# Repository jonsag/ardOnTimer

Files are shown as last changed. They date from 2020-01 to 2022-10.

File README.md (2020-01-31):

# ardOnTimer
An on timer with relay, mainly for use in an UV exposure box.  

Time is set with buttons and visualized on an LCD display.  

When setting new time it's saved in eeprom and reloaded at startup.  

Timer range is from 10 seconds to 9 hours, 59 minutes and 59 seconds in 10 seconds steps.  
This can be changed in configuration file.  

Parts list
==========
1 x Arduino Uno, kjell.com art#88860  
1 x LCD display 2x16 characters, kjell.com art# 90215  
1 x Relay module KY-019, kjell.com art# 87878  
1 x Buzzer, kjell.com art# 87887  
4 x Switch, kjell.com art# 36011  
1 x 10kohm potentiometer  
4 x 10kohm resistor  
1 x 220ohm resistor  
1x 100ohm resistor  

Screens
==========
The timer has three screens.  
Second row on screens shows which buttons are active.  

Standby screen
----------
Waiting for start or set.  

 * Start/Stop/Store button to start timer and enter run screen.  
 * Set button to enter set screen.  

Run screen
----------
Shows spinning bar and time left on first row, and progressbar on the second.  

 * Start/Stop/Store button to stop timer and go back to standby screen.  

Set screen
----------
Setting timer.  

* Start/Stop/Store button to store set time.  
* Set button to exit back to standby screen. If set time was not stored, previous time will be used.  
* Up or Down button to increase/decrease time. Each press adds/subtracts 10 seconds from time. Long press adds/subtracts one minute from time. Holding down button keeps stepping minutes.

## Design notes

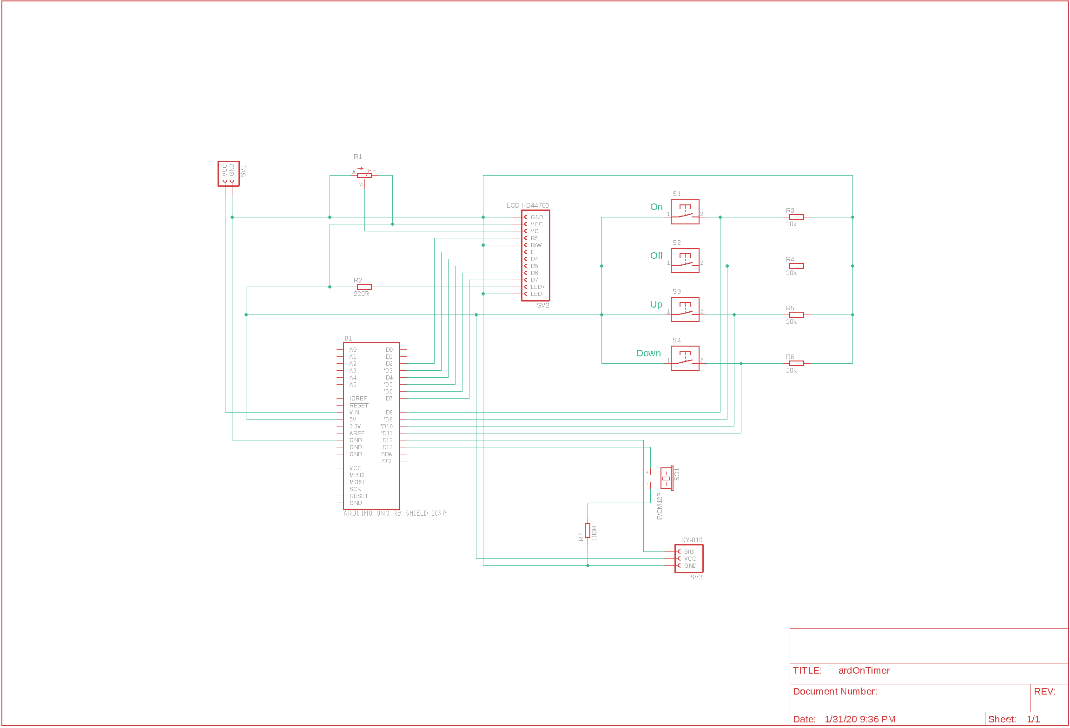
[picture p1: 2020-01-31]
Documents/ardOnTimer schematics.png

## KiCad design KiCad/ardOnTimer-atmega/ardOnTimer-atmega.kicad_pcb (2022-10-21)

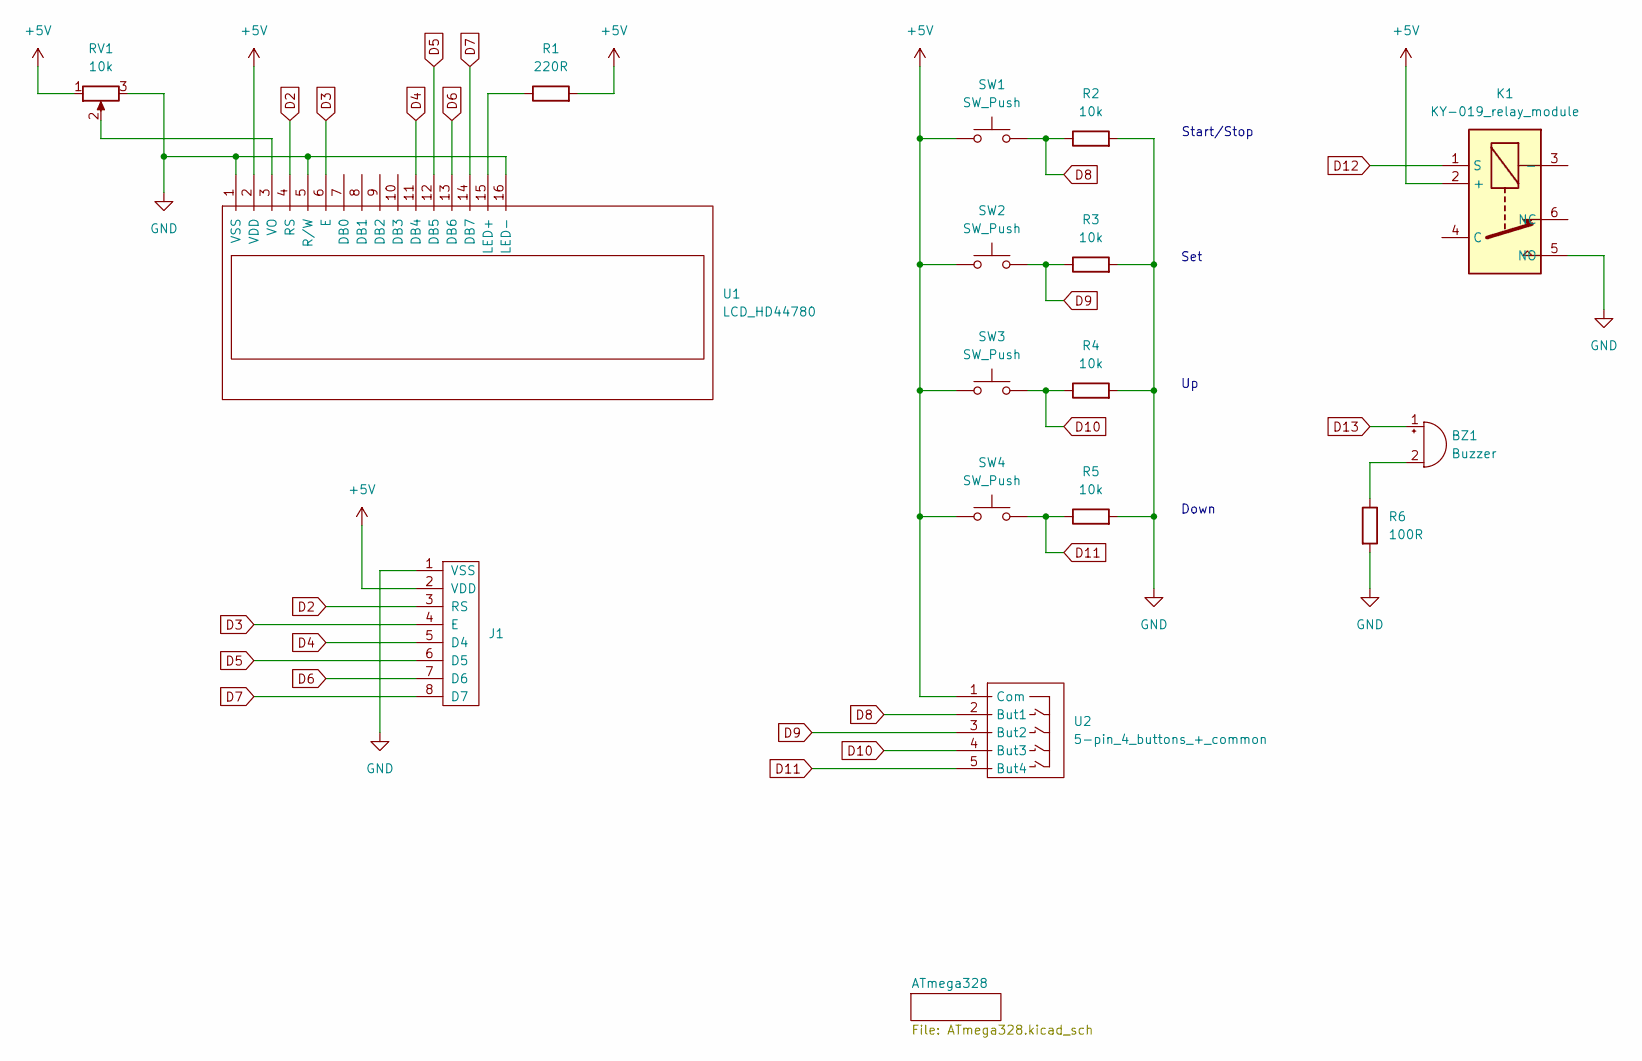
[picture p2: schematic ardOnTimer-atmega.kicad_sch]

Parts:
BZ1: Buzzer; Buzzer_TDK_PS1240P02BT_D12.2mm_H6.5mm_large
J1: 8-pin_header_LCD_interface; 8-pin JST LCD
K1: KY-019_relay_module; KY-019_Relay_module_w_header_large
R1: 220R; R_Axial_DIN0207_L6.3mm_D2.5mm_P10.16mm_Horizontal_larger_pa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
R2, R3, R4, R5: 10k; R_Axial_DIN0207_L6.3mm_D2.5mm_P10.16mm_Horizontal_larger_pa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
R6: 100R; R_Axial_DIN0207_L6.3mm_D2.5mm_P10.16mm_Horizontal_larger_pa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
RV1: 10k; Potentiometer_Bourns_3339P_Vertical_large
SW1, SW2, SW3, SW4: SW_Push; SW_PUSH_6mm_large
U1: LCD_HD44780; LCD_HD44780_16x2_w_headers_large
U2: 5-pin_4_buttons_+_common; 5-pin JST 4 buttons + common

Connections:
+5V: J1.2 (VDD), K1.2 (+), R1.2, RV1.1, SW1.1, SW2.1, SW3.1, SW4.1, U1.2 (VDD), U2.1 (Com); also elsewhere on the board
D2: J1.3 (RS), U1.4 (RS); also elsewhere on the board
D3: J1.4 (E), U1.6 (E); also elsewhere on the board
D4: J1.5 (D4), U1.11 (DB4); also elsewhere on the board
D5: J1.6 (D5), U1.12 (DB5); also elsewhere on the board
D6: J1.7 (D6), U1.13 (DB6); also elsewhere on the board
D7: J1.8 (D7), U1.14 (DB7); also elsewhere on the board
D8: R2.1, SW1.2, U2.2 (But1); also elsewhere on the board
D9: R3.1, SW2.2, U2.3 (But2); also elsewhere on the board
D10: R4.1, SW3.2, U2.4 (But3); also elsewhere on the board
D11: R5.1, SW4.2, U2.5 (But4); also elsewhere on the board
D12: K1.1 (S); also elsewhere on the board
D13: BZ1.1 (-); also elsewhere on the board
GND: J1.1 (VSS), K1.5 (NO), R2.2, R3.2, R4.2, R5.2, R6.2, RV1.3, U1.1 (VSS), U1.5 (R/W), U1.16 (LED-); also elsewhere on the board
unnamed: BZ1.2 (+), R6.1
unnamed: R1.1, U1.15 (LED+)
unnamed: RV1.2, U1.3 (VO)

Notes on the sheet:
Start/Stop
Down
Set

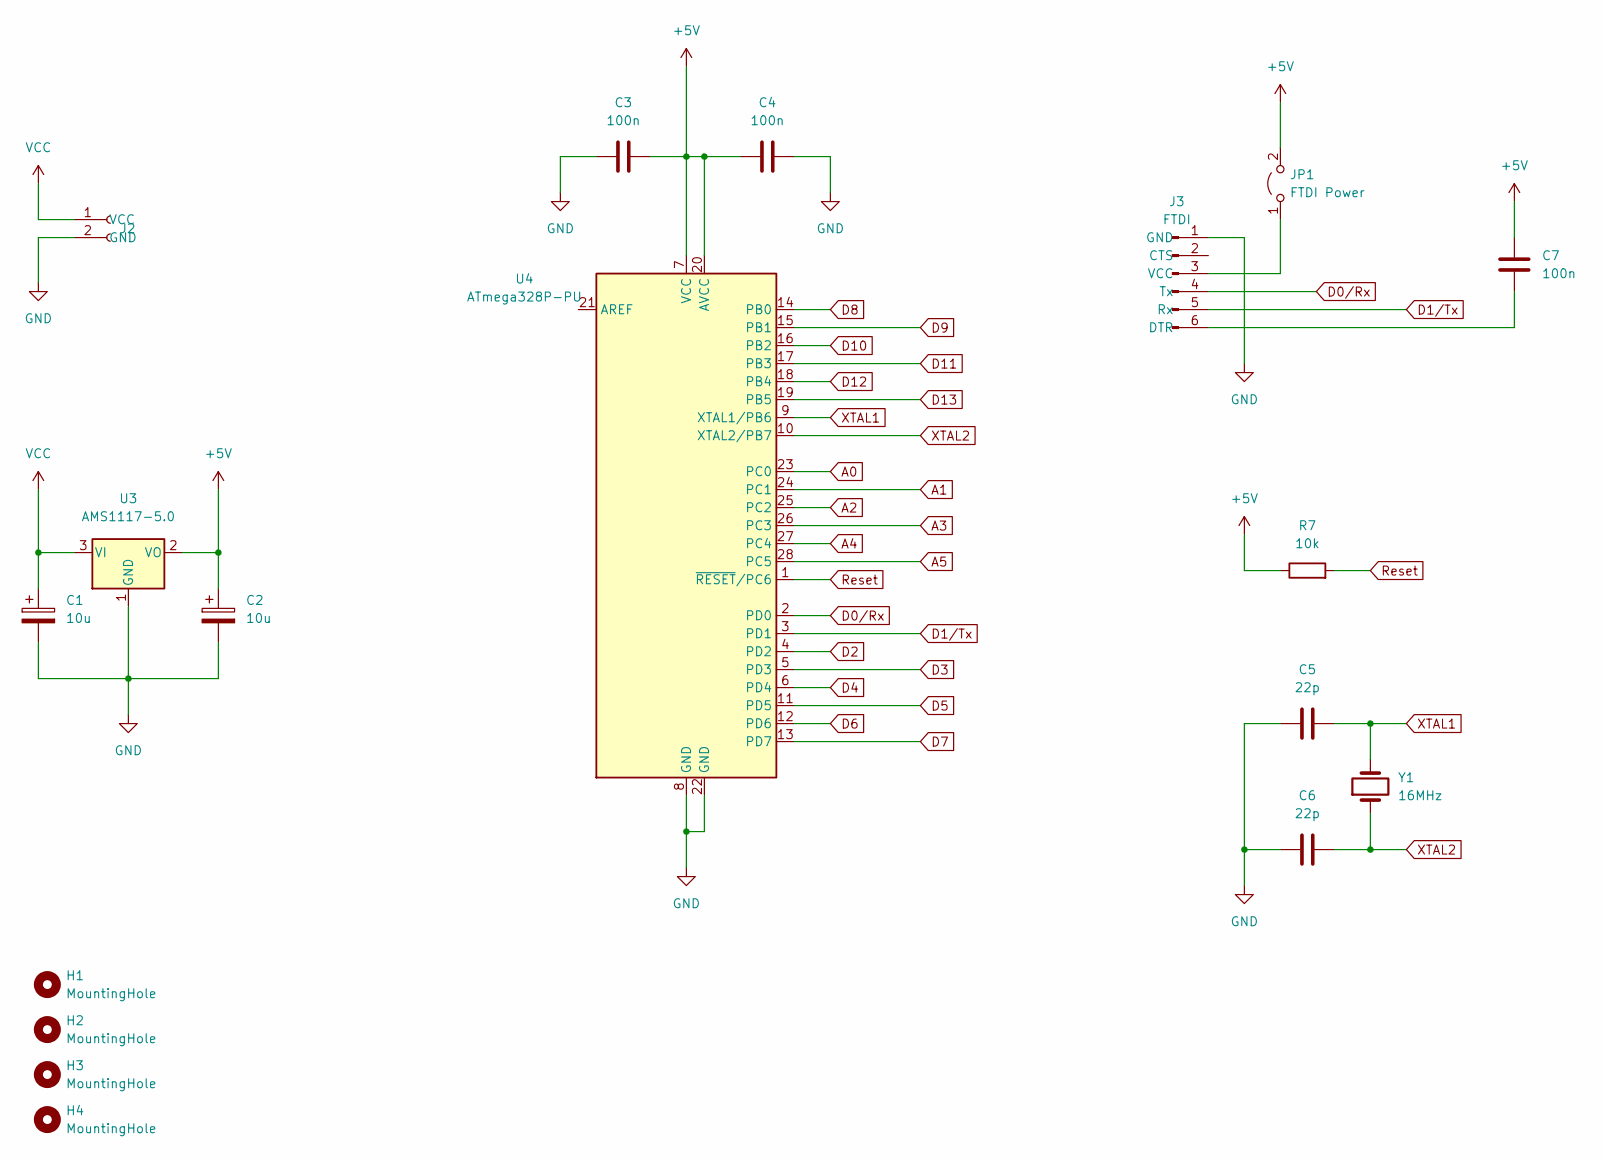
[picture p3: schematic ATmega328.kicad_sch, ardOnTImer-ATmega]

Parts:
C1, C2: 10u; CP_Radial_D5.0mm_P2.00mm_larger
C3, C4, C7: 100n; C_Disc_D4.3mm_W1.9mm_P5.00mm_large
C5, C6: 22p; C_Disc_D3.0mm_W1.6mm_P2.50mm_larg
H1, H2, H3, H4: MountingHole; MountingHole_3.2mm_M3
J2: Power in; BarrelJack_Horizontal
J3: FTDI; 6-pin FTDI Programmer PinSocket large
JP1: FTDI Power; Jumper_1x02_P2.54mm_large
R7: 10k; R_Axial_DIN0207_L6.3mm_D2.5mm_P10.16mm_Horizontal_larger_pa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
U3: AMS1117-5.0; SOT-223-3_TabPin2
U4: ATmega328P-PU; DIP-28_W7.62mm_LongPads w socket
Y1: 16MHz; Crystal_HC49-4H_Vertical_large

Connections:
+5V: C2.1, C3.1, C4.2, C7.2, JP1.2 (B), R7.1, U3.2 (VO), U4.7 (VCC), U4.20 (AVCC); also elsewhere on the board
A0: U4.23 (PC0)
A1: U4.24 (PC1)
A2: U4.25 (PC2)
A3: U4.26 (PC3)
A4: U4.27 (PC4)
A5: U4.28 (PC5)
D0/Rx: J3.4 (Tx), U4.2 (PD0)
D1/Tx: J3.5 (Rx), U4.3 (PD1)
D2: U4.4 (PD2); also elsewhere on the board
D3: U4.5 (PD3); also elsewhere on the board
D4: U4.6 (PD4); also elsewhere on the board
D5: U4.11 (PD5); also elsewhere on the board
D6: U4.12 (PD6); also elsewhere on the board
D7: U4.13 (PD7); also elsewhere on the board
D8: U4.14 (PB0); also elsewhere on the board
D9: U4.15 (PB1); also elsewhere on the board
D10: U4.16 (PB2); also elsewhere on the board
D11: U4.17 (PB3); also elsewhere on the board
D12: U4.18 (PB4); also elsewhere on the board
D13: U4.19 (PB5); also elsewhere on the board
GND: C1.2, C2.2, C3.2, C4.1, C5.1, C6.1, J2.2 (GND), J3.1 (GND), U3.1 (GND), U4.8 (GND), U4.22 (GND); also elsewhere on the board
unnamed: C7.1, J3.6 (DTR)
unnamed: J3.3 (VCC), JP1.1 (A)
Reset: R7.2, U4.1 (~RESET/PC6)
VCC: C1.1, J2.1 (VCC), U3.3 (VI)
XTAL1: C5.2, U4.9 (XTAL1/PB6), Y1.2
XTAL2: C6.2, U4.10 (XTAL2/PB7), Y1.1

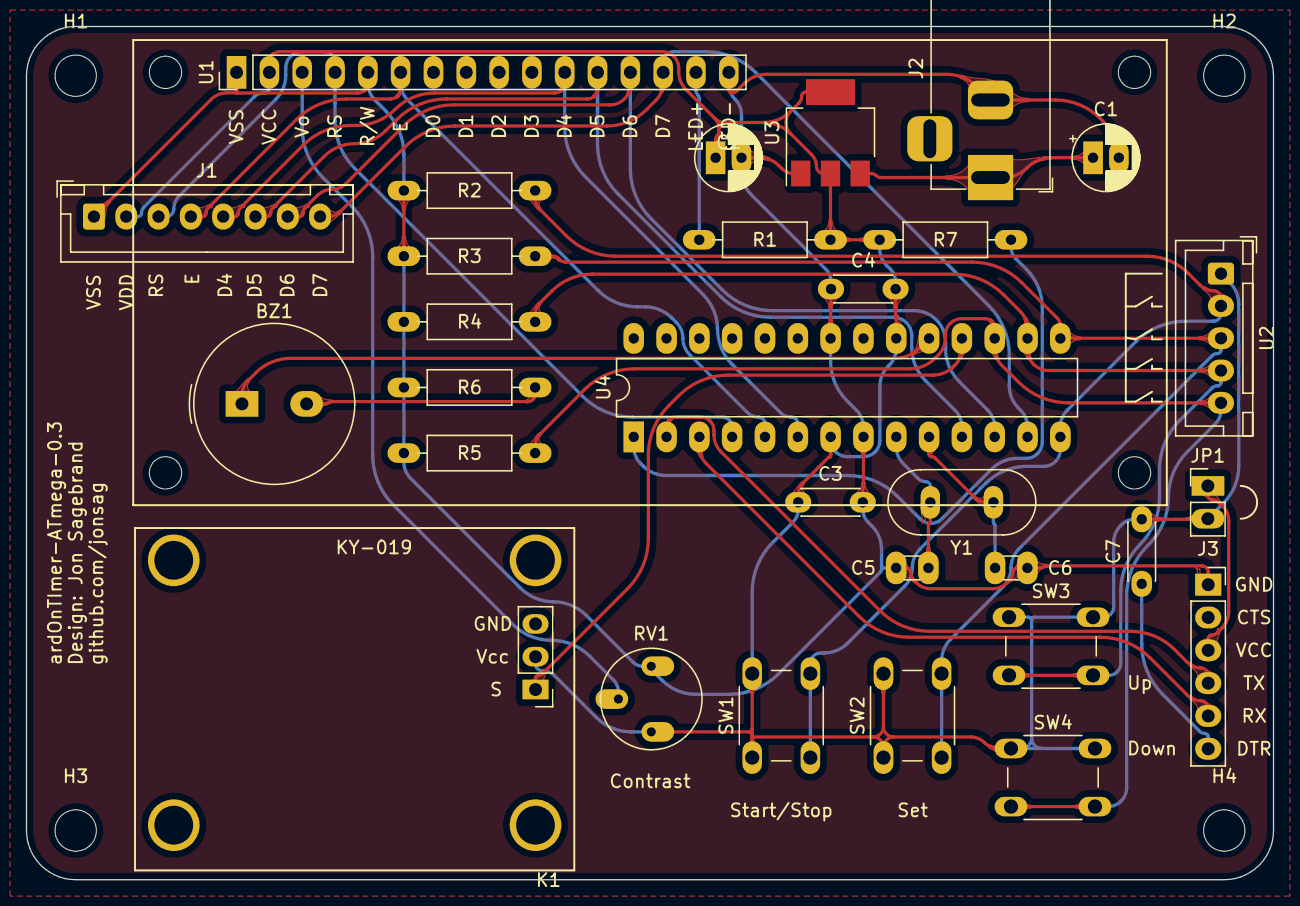
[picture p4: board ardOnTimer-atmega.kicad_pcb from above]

Board: 2 copper layers, 96.5 x 66.0 mm, 34 parts (0 on the bottom side), 25 nets.

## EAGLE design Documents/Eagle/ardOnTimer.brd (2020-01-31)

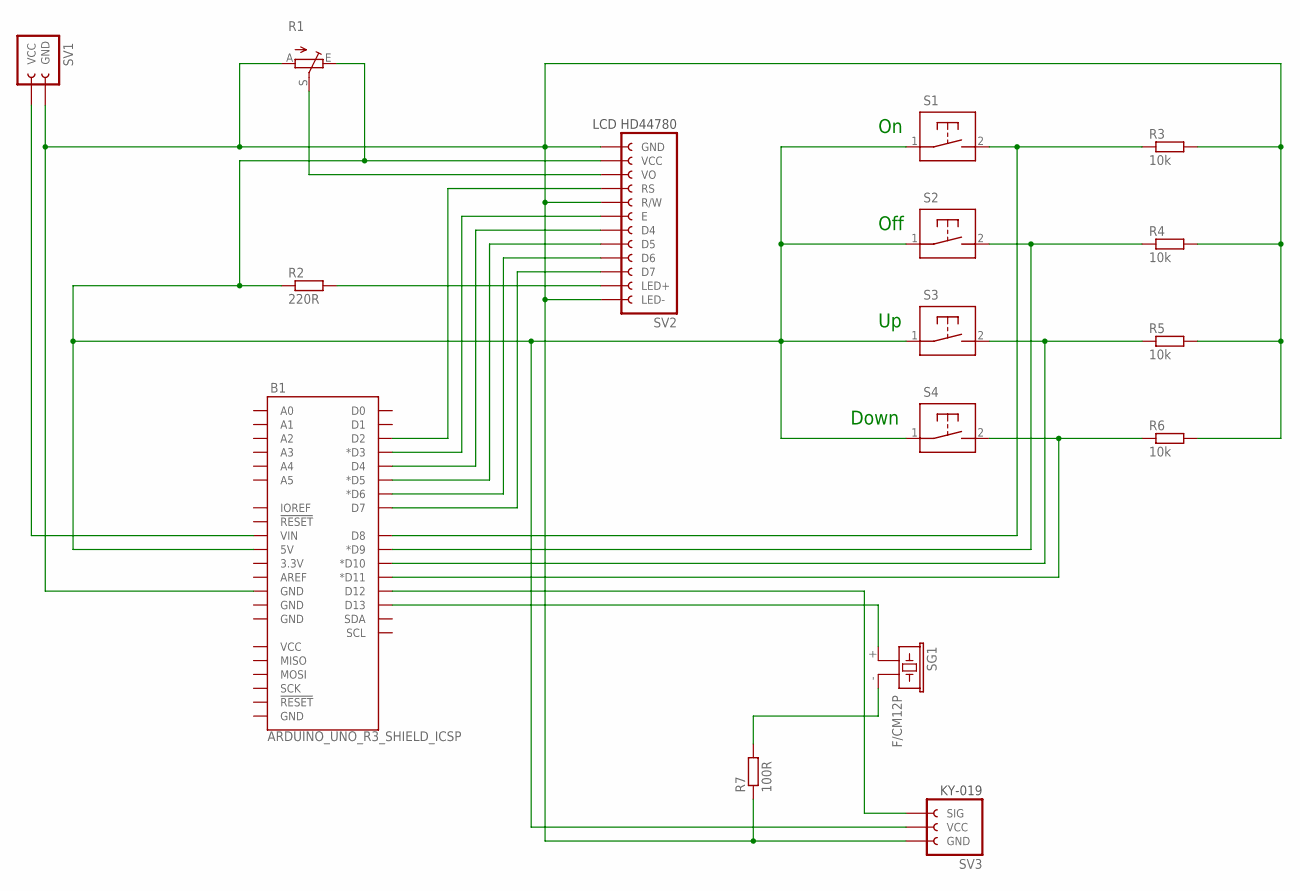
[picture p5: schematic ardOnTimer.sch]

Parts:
B1: ARDUINO_UNO_R3_SHIELD_ICSP; UNO_R3_SHIELD_ICSP
R1: POTENTIOMETER_CA6VCA6V; CA6V
R2: 220R; 0204/7
R3, R4, R5, R6: 10k; 0204/7
R7: 100R; 0204/7
S1, S2, S3, S4: NO_SWITCH_2-PIN-FEMALE_HEADER
SG1: F/CM12P
SV1: POWER_IN-2-PIN_FEMALE_HEADER
SV2: LCD-HD44780-12-PIN_FEMALE_HEADER
SV3: KY-019_3-PIN_FEMALE_HEADERANGLED_W_MOUNT_HOLES; KY-019_3-PIN_FEMALE_HEADER_ANGLED_W_MOUNT_HOLES

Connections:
unnamed: B1.GND@2 (GND), R1.A, R3.2, R4.2, R5.2, R6.2, R7.1, SV1.GND, SV2.GND, SV2.LED-, SV2.R/W, SV3.GND
unnamed: B1.D13, SG1.+ (1)
unnamed: R1.S, SV2.VO
unnamed: R2.2, SV2.LED+
unnamed: B1.D2, SV2.RS
unnamed: B1.D3 (*D3), SV2.E
unnamed: B1.D4, SV2.D4
unnamed: B1.D5 (*D5), SV2.D5
unnamed: B1.D6 (*D6), SV2.D6
unnamed: B1.D7, SV2.D7
unnamed: B1.VIN, SV1.VCC
unnamed: B1.5V, R1.E, R2.1, S1.1, S2.1, S3.1, S4.1, SV2.VCC, SV3.VCC
unnamed: B1.D8, R3.1, S1.2 (S)
unnamed: B1.D9 (*D9), R4.1, S2.2 (S)
unnamed: B1.D10 (*D10), R5.1, S3.2 (S)
unnamed: B1.D11 (*D11), R6.1, S4.2 (S)
unnamed: B1.D12, SV3.SIG
unnamed: R7.2, SG1.- (2)

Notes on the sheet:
Off
Down

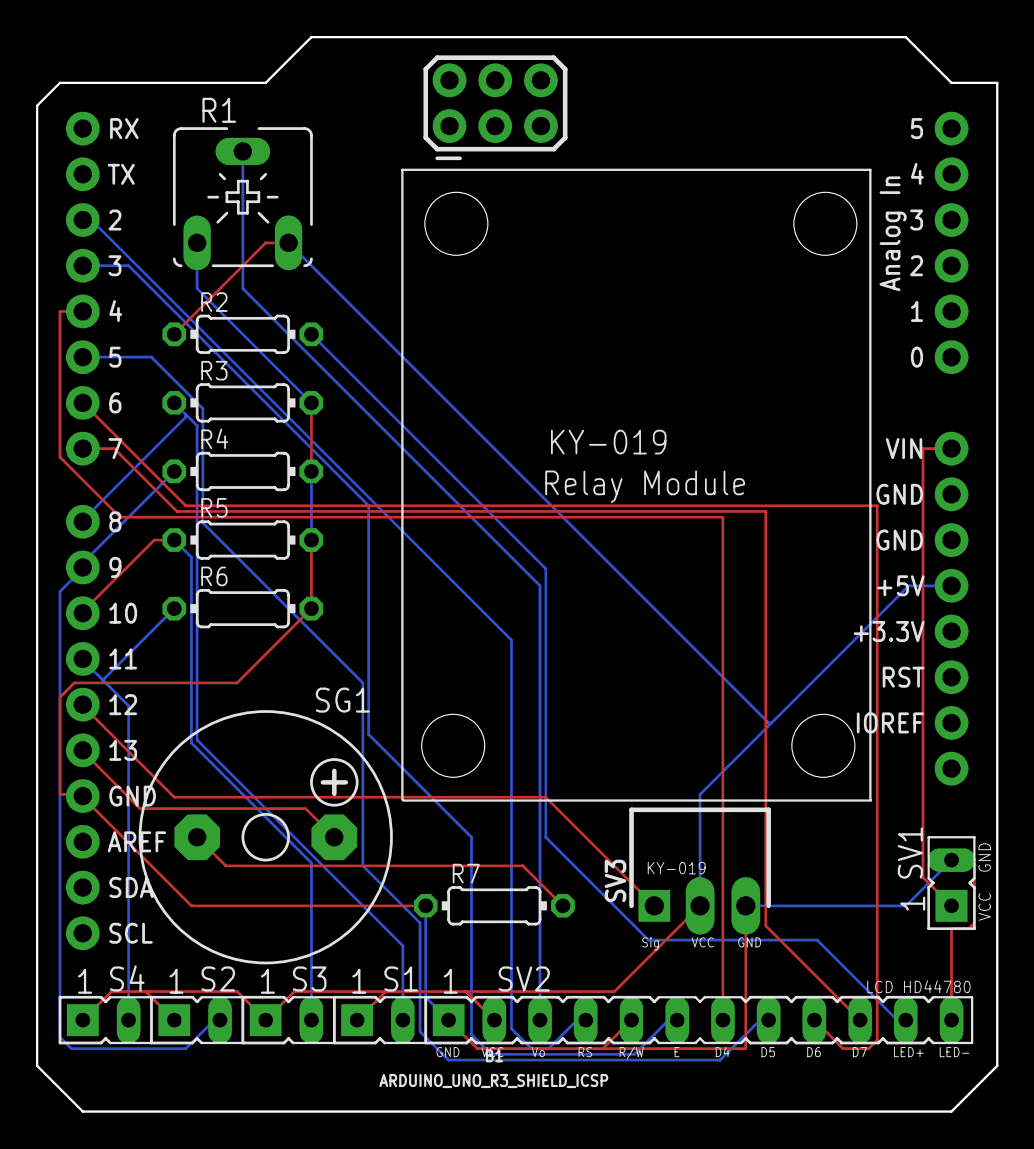
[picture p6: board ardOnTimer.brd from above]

Board: 2 copper layers, 53.3 x 59.7 mm, 16 parts (0 on the bottom side), 18 nets.

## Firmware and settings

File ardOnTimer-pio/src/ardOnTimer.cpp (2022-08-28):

#include "Arduino.h"

#include "configuration.h" // sets all variables
#include "buttons.h"       // handles the button presses
#include "lcd.h"           // manages all info om LCD
#include "run.h"           // handles the timer function

void setup()
{
  /*******************************
    Start LCD
  *******************************/
  lcd.begin(lcdColumns, lcdRows);
  lcd.setCursor(0, 0); // print name of this program and boot message to the LCD
  lcd.print(programName);
  lcd.setCursor(0, 1);
  lcd.print("Booting ...");

  /*******************************
    Start serial
  *******************************/
  lcd.setCursor(0, 1);
  lcd.print("Starting serial ");

  Serial.begin(9600);

  Serial.println(programName); // print information
  Serial.println(date);
  Serial.print("by ");
  Serial.print(author);
  Serial.println(email);
  Serial.println();

  /*******************************
    Define in- and outputs
  *******************************/
  lcd.setCursor(0, 1);
  lcd.print("Starting in/out ");
  Serial.println("Starting in- and outputs...");
  Serial.println();

  pinMode(startButtonPin, INPUT);
  pinMode(setButtonPin, INPUT);
  pinMode(upButtonPin, INPUT);
  pinMode(downButtonPin, INPUT);
  pinMode(buzzerPin, OUTPUT);
  pinMode(relayPin, OUTPUT);

  digitalWrite(relayPin, relayState); // set initial output states

  /*******************************
    Read time value from eeprom
  *******************************/
  lcd.setCursor(0, 1);
  lcd.print("Reading EEPROM  ");
  Serial.println("Reading last time from eeprom ...");

  f = 0.00f;
  EEPROM.get(eeAddr, f); // read time from eeprom
  Serial.print("Found time: ");
  Serial.print(f);
  Serial.print(" seconds");
  Serial.println();

  if (isnan(f))
  { // check if there is a value stored in eeprom
    Serial.println("No value found in eeprom");
    Serial.print("Storing value: ");
    Serial.println(dur);
    Serial.println();
    EEPROM.put(eeAddr, dur); // if not, store the predefined time
  }
  else
  {
    Serial.println("Using it for timer");
    Serial.println();
    dur = f; // else use it as set point
  }

  /*******************************
      Build custom characters
    *******************************/
  lcd.setCursor(0, 1);
  lcd.print("Building chars  ");
  Serial.println("Building characters ...");
  Serial.println();

  lcd.createChar(1, customOneDot);
  lcd.createChar(2, customTwoDots);
  lcd.createChar(3, customThreeDots);
  lcd.createChar(4, customFourDots);
  lcd.createChar(5, customUpArrow);
  lcd.createChar(6, customDownArrow);
  lcd.createChar(7, customBackslash);

  lcd.clear();
}

void loop()
{
  /*******************************
    Read buttons
  *******************************/
  readButtons();

  if (relayState == HIGH)
  { // timer is running
    runScreen();
    countDown();
  }
  else if (setMode == HIGH)
  { // in set mode
    setScreen();
    // setTime();
  }
  else
  {
    waitScreen();
  }
}

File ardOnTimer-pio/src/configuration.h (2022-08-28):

String programName = "ardOnTimer";
String date = "20200130";
String author = "Jon Sagebrand";
String email = "jonsagebrand@gmail.com";

/*******************************
   EEPROM setup
 *******************************/
#include <EEPROM.h>   // include EEPROM library
const int eeAddr = 0; // address to store the time
int f;                // stores the time set in eeprom

/*******************************
   LCD setup
 *******************************/
// include the LCD library
#include <LiquidCrystal.h>
// set LCD pins
int LCD_RS = 2; // LCD RS, pin 4
int LCD_EN = 3; // LCD E, pin 6, Enable
int LCD_D4 = 4; // LCD D4, pin 11, databit 4
int LCD_D5 = 5; // LCD D5, pin 12, databit 5
int LCD_D6 = 6; // LCD D6, pin 13, databit 6
int LCD_D7 = 7; // LCD D7, pin 14, databit7
/* other pins on LCD are:
   VSS, pin 1, GND
   VDD, pin 2, +5V
   V0, pin 3, 10k potentiometer, ends to +5V and GND, middle pin to V0, contrast
   R/W, pin 5, GND, Read/Write
   A, pin 15, 220ohm resistor, one end to +5V, other to A, back light anode, ~+4.2V
   K, pin 16, GND, back light cathode
   D0, pin 7, databit 0, not used/connected
   D1, pin 8, databit 1, not used/connected
   D2, pin 9, databit 2, not used/connected
   D3, pin 10, databit 3, not used/connected
*/
// initialize the library with the numbers of the interface pins
LiquidCrystal lcd(LCD_RS, LCD_EN, LCD_D4, LCD_D5, LCD_D6, LCD_D7);
// columns and rows of the LCD
int lcdColumns = 16;
int lcdRows = 2;

/*******************************
   Buttons setup
 *******************************/
const int startButtonPin = 8;
const int setButtonPin = 9;
const int upButtonPin = 10;
const int downButtonPin = 11;

int startButtonReading;
int startButtonState; // the current reading from the start/stop/store button pin
int lastStartButtonState = LOW;

int setButtonReading;
int setButtonState; // the current reading from the set button pin
int lastSetButtonState = LOW;

int upButtonReading;
int upButtonState; // the current reading from the up button pin
int lastUpButtonState = LOW;
unsigned long repeatUpButton; // when was the button pressed

int downButtonReading;
int downButtonState; // the current reading from the down button pin
int lastDownButtonState = LOW;
unsigned long repeatDownButton; // when was the button pressed

/*******************************
   Buzzer setup
 *******************************/
const int buzzerPin = 13;

/*******************************
   Relay setup
 *******************************/
const int relayPin = 12;
int relayState = LOW; // the current state of the relay pin

/*******************************
   Debouncing
 *******************************/
unsigned long lastStartDebounceTime = 0; // the last time the output pin was toggled
unsigned long lastSetDebounceTime = 0;   // the last time the output pin was toggled
unsigned long lastUpDebounceTime = 0;    // the last time the output pin was toggled
unsigned long lastDownDebounceTime = 0;  // the last time the output pin was toggled

unsigned long debounceDelay = 20; // the debounce time; increase if the output flickers

/*******************************
   Tones
 *******************************/
const int startTone = 1500;
const int startLength = 200;

const int stopTone = 1500;
const int stopLength = 500;

const int setTone = 1750;
const int setLength = 200;

const int storeTone = 1750;
const int storeLength = 500;

const int upTone = 2000;
const int upLength = 100;

const int downTone = 1000;
const int downLength = 100;

const int errorTone = 500;
const int errorLength = 500;

/*******************************
   Times
 *******************************/
int dur = 180;      // default timer on-time
int timeLeft = dur; // counts down when timer is running

int seconds; // for converting seconds to hours, minutes and seconds
int h;
int m;
int s;
int t;

int newDur = dur;     // used when setting time
const int incr1 = 10; // increments for counting up/down
const int incr2 = 60;

int repeatTime = 500; // time to hold button down for increased speed

unsigned long startMillis; // used when timer is running

unsigned long animationMillis; // for animation in run screen

const unsigned int maxSeconds = 35999 - incr2; // max allowed value for timer, in seconds, min is 1 second (35999 = 9 hrs, 59 min, 59 sec, 65535 = 18 hrs, 12 min, 15 sec)

/*******************************
   Custom characters
 *******************************/
byte customUpArrow[8] = {
    0b00100,
    0b01110,
    0b10101,
    0b00100,
    0b00100,
    0b00100,
    0b00100,
    0b00000};

byte customDownArrow[8] = {
    0b00100,
    0b00100,
    0b00100,
    0b00100,
    0b10101,
    0b01110,
    0b00100,
    0b00000};

byte customBackslash[8] = {
    0b00000,
    0b10000,
    0b01000,
    0b00100,
    0b00010,
    0b00001,
    0b00000,
    0b00000};
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

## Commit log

2020-01-26 added example
    [Exposure Timer Button Panel.brd, Exposure Timer Button Panel.sch, Exposure Timer.brd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]
2020-01-26 split code
    [configuration.h]
2020-01-27 sketch update
    [configuration.h]
2020-01-28 mostly working sketch
    [configuration.h]
2020-01-28 added Eagle schematics
    [ardOnTimer.brd, ardOnTimer.sch]
2020-01-29 Sketch stores new value in eeprom. Enhanced lcd layout
    [configuration.h]
2020-01-29 Output change. Bugs
    [configuration.h]
2020-01-30 now speeds up when holding up/down buttons
    [configuration.h]
2020-01-30 Animates run. Up, down arrows. Fast setting.
    [configuration.h]
2020-01-30 Addded progress bar (not tested yet)
    [configuration.h]
2020-01-31 Progressbar working
    [configuration.h]
2020-01-31 Deleted older project
    [Exposure Timer Button Panel.brd, Exposure Timer Button Panel.sch, Exposure Timer.brd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]
2020-01-31 Switched DI12<->DI13
    [ardOnTimer.brd, ardOnTimer.sch]
2020-01-31 Forgot resistor in schematics. Updated readme.
    [ardOnTimer.brd, ardOnTimer.sch]
2022-08-28 kicad schematics
    [ATmega328.kicad_sch, ardOnTimer-atmega.kicad_pcb, ardOnTimer-atmega.kicad_sch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]
2022-10-21 kicad v0.3
    [ATmega328.kicad_sch, ardOnTimer-atmega.kicad_pcb, ardOnTimer-atmega.kicad_sch]
